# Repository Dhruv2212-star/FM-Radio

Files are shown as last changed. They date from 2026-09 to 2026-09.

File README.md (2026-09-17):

# Dhruv's FM-Radio 
A simple FM radio that can search for channels and connect to them with the given controls from 87-108 MHz that can fit in your palms !  

## Virtual Controls for our radio-  
1.  s = seek up  
2.  S = seek down  
3. "+" = tune +100 kHz  
4.  "-" = tune -100 kHz  
5.  V = increase RDA5807 digital volume  
6.  v = decrease RDA5807 digital volume  
7.  m = mute/unmute  
8.  i = print radio status

**PCB Dimentions- 40mm x 55mm x 1.6 mm**  

# How to use the final Radio?
To use the final radio, connect the microcontroller to your laptop/desktop and flash the firmware on and it'll show a new panel, you can use the above keys for the controls  

## Case
our case is made into 2 parts, the Bottom case and the Top case, the top case will snugly fit on the bottom case because of it's low tolerance 

**Top Case**  


**Bottom Case** 



# Final Assembly 
what our final product will look like (ignore the empty spaces, its for speakers) 
Image of proj

## PCB 


14 09 2026_14 19 05_REC

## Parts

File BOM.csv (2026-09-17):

Ref | Value | Description | Qty | KiCad Symbol | Footprint | India seller | Unit cost (INR) | Buy / product page
U1 | MOUDLE-SEEEDUINO-XIAO | Seeed Studio XIAO RP2040 | 1 | XIAO_RP2040:MOUDLE-SEEEDUINO-XIAO | my footprints:XIAO-Generic-Hybrid-14P-2.54-21X17.8MM | Robocraze | INR 589 | https://robocraze.com/pages/seeed-studio
U2 | RDA5807MRRD-102V2.0 | RDA5807M RRD-102 V2.0 FM module | 1 | Static_Symbol_Library:RDA5807MRRD-102V2.0 | Static:RDA5807 | ElectronicsComp | INR 67.26 | https://www.electronicscomp.com/rda5807m-fm-stereo-radio-module-rrd-102v2.0-wireless-pro-for-arduino-tuner
U3 | TDA2822NBD | TDA2822 dual audio amplifier, DIP-8 | 1 | Static_Symbol_Library:TDA2822NBD | Package_DIP:DIP-8_W7.62mm | Robu.in (equivalent TDA2822M) | INR 9 | https://robu.in/product-category/electronic-components/integrated-circuits/audio-ic/
RV1 | 10K | WH148 10K potentiometer | 1 | Device:R_Potentiometer | Connector:FanPinHeader_1x03_P2.54mm_Vertical | AM Electronics India | INR 12 | https://amelectronics.in/product/10k-potentiometer/
RV2 | 10K | WH148 10K potentiometer | 1 | Device:R_Potentiometer | Connector:FanPinHeader_1x03_P2.54mm_Vertical | AM Electronics India | INR 12 | https://amelectronics.in/product/10k-potentiometer/
C1 | 100uF | 100 µF polarized electrolytic capacitor | 1 | Device:C_Polarized | Capacitor_THT:CP_Radial_D6.3mm_P2.50mm | ElectronicsComp | INR 3.74 | https://www.electronicscomp.com/100uf-16v-electrolytic-capacitor
C2 | 100uF | 100 µF polarized electrolytic capacitor | 1 | Device:C_Polarized | Capacitor_THT:CP_Radial_D6.3mm_P2.50mm | ElectronicsComp | INR 3.74 | https://www.electronicscomp.com/100uf-16v-electrolytic-capacitor
C3 | 100uF | 100 µF polarized electrolytic capacitor | 1 | Device:C_Polarized | Capacitor_THT:CP_Radial_D6.3mm_P2.50mm | ElectronicsComp | INR 3.74 | https://www.electronicscomp.com/100uf-16v-electrolytic-capacitor
C4 | 100uF | 100 µF polarized electrolytic capacitor | 1 | Device:C_Polarized | Capacitor_THT:CP_Radial_D6.3mm_P2.50mm | ElectronicsComp | INR 3.74 | https://www.electronicscomp.com/100uf-16v-electrolytic-capacitor
C5 | 100uF | 100 µF polarized electrolytic capacitor | 1 | Device:C_Polarized | Capacitor_THT:CP_Radial_D6.3mm_P2.50mm | ElectronicsComp | INR 3.74 | https://www.electronicscomp.com/100uf-16v-electrolytic-capacitor
CN1 | PJ-3200 | 3.5 mm stereo audio jack, PJ-3200 | 1 | Static_Symbol_Library:PJ-3200 | Static:AUDIO-TH_PJ-3200 | Evelta | INR 4.72 | https://evelta.com/3-5mm-female-audio-jack-connector-3pin-1/
TP1 | SP1 + | SMD solder pad, 4x4 mm | 1 | Connector:TestPoint | TestPoint:TestPoint_Pad_4.0x4.0mm |  |  | https://kicad.github.io/footprints/TestPoint.html
TP2 | SP - | SMD solder pad, 4x4 mm | 1 | Connector:TestPoint | TestPoint:TestPoint_Pad_4.0x4.0mm |  |  | https://kicad.github.io/footprints/TestPoint.html
TP3 | SP2 + | SMD solder pad, 4x4 mm | 1 | Connector:TestPoint | TestPoint:TestPoint_Pad_4.0x4.0mm |  |  | https://kicad.github.io/footprints/TestPoint.html
TP4 | SP2 - | SMD solder pad, 4x4 mm | 1 | Connector:TestPoint | TestPoint:TestPoint_Pad_4.0x4.0mm |  |  | https://kicad.github.io/footprints/TestPoint.html
TOTAL COST |  |  |  |  |  |  | INR 712.68

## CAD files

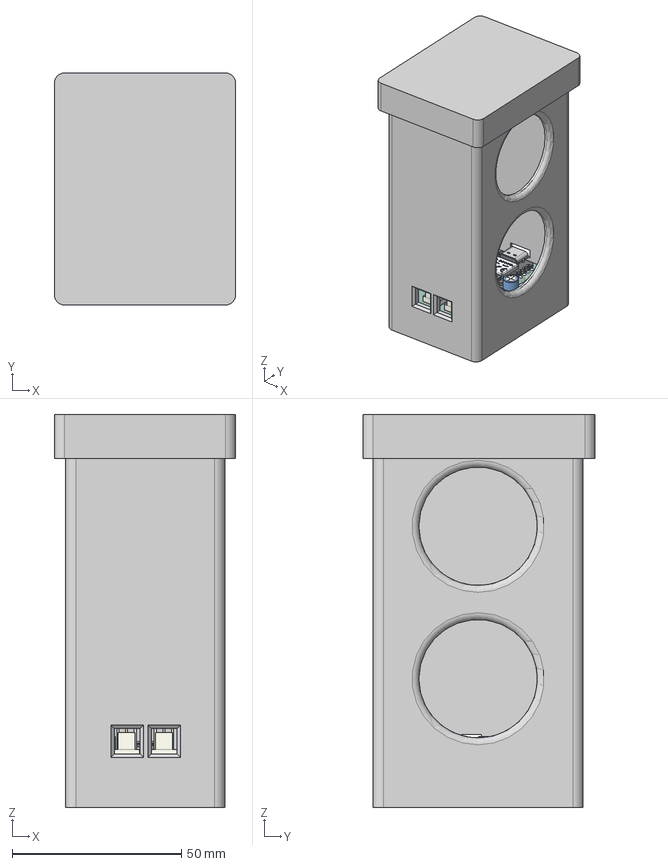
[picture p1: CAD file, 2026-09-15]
Src files/CAD/Assembly File_.step
53.5 x 68.5 x 116.0 mm
Radio_via
Radio_PCB
VSS

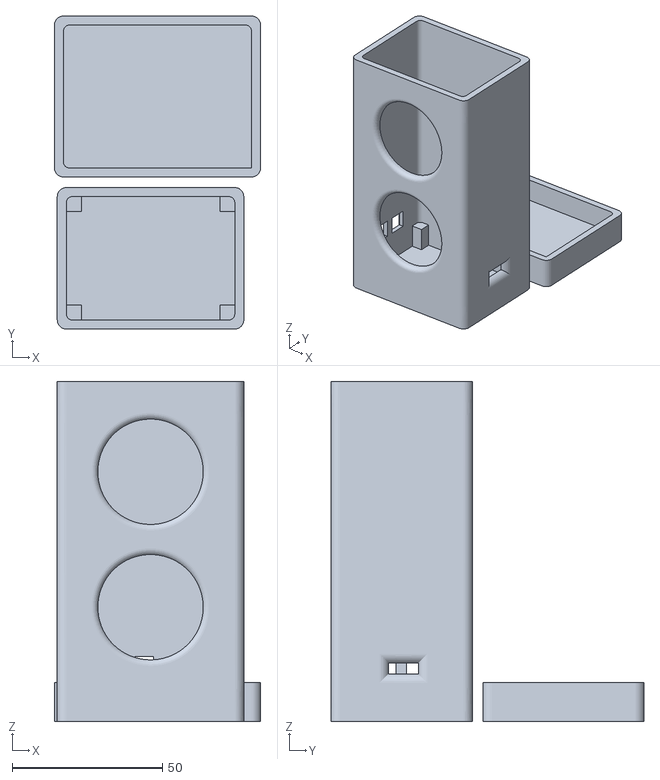
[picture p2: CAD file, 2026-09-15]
Production/Case.stl
68.5 x 104.0 x 113.0

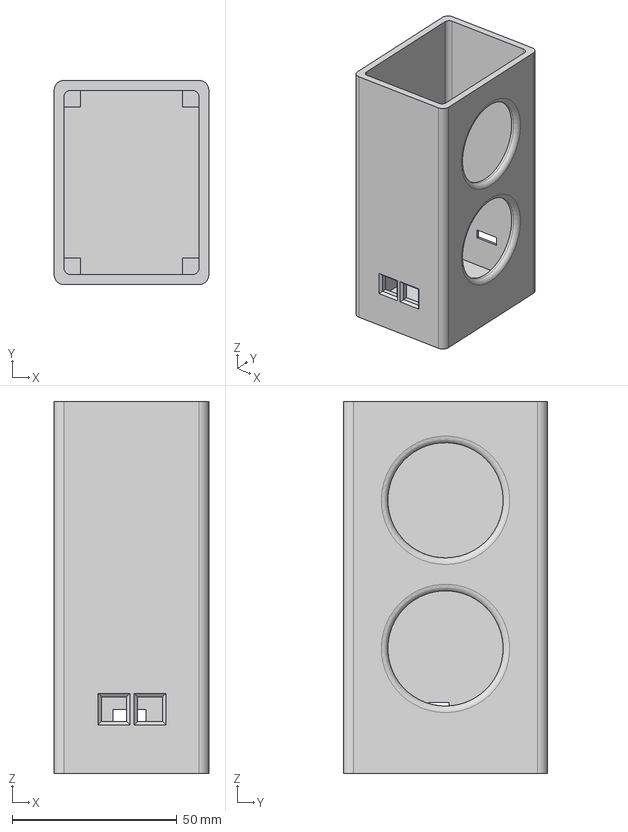
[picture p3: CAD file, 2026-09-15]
Src files/CAD/Case/Bottom case.step
47.0 x 62.0 x 113.0 mm

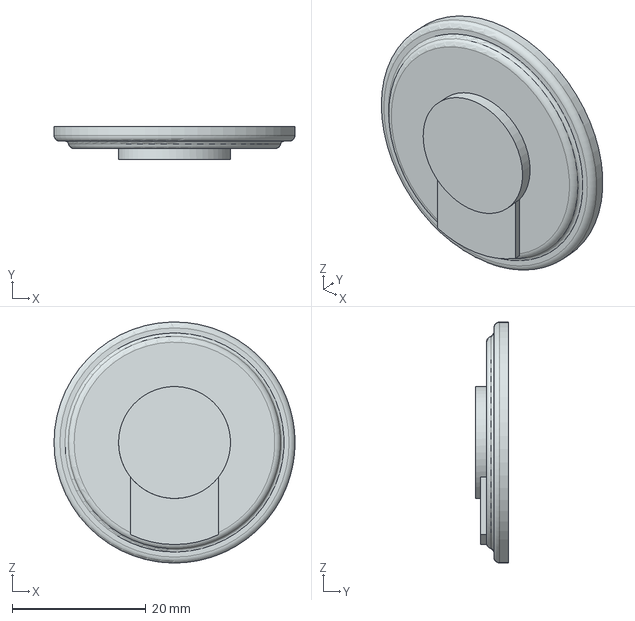
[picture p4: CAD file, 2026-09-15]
Src files/CAD/Models related to PCB/16 ohm 36 mm speaker.stp
36.0 x 4.95 x 36.0 mm

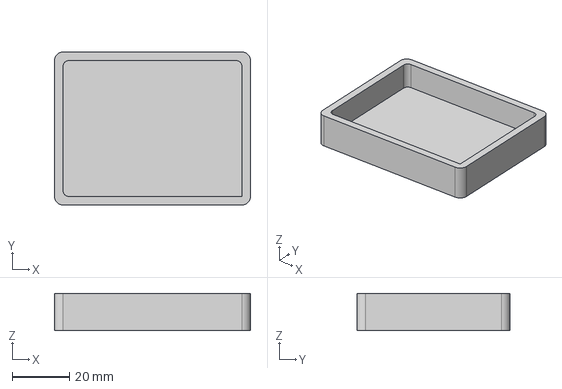
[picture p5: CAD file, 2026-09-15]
Src files/CAD/Case/Top case.step
68.5 x 53.5 x 13.0 mm

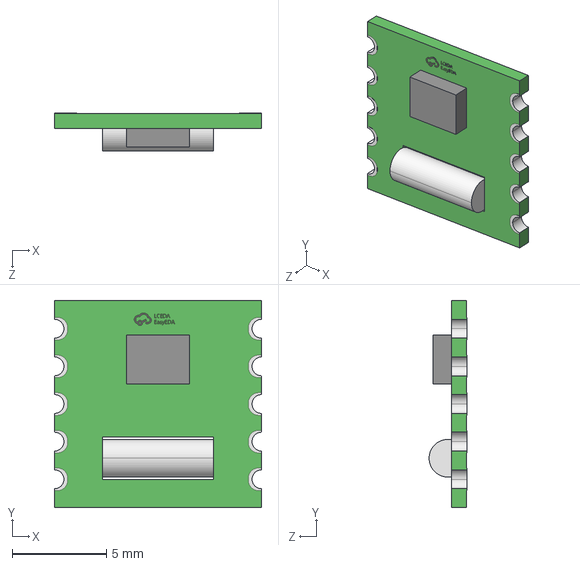
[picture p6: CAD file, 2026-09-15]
Src files/CAD/Models related to PCB/COMM-SMD_L11.0-W11.0-P2.00-TL.step
11.0 x 11.0 x 2.01 mm

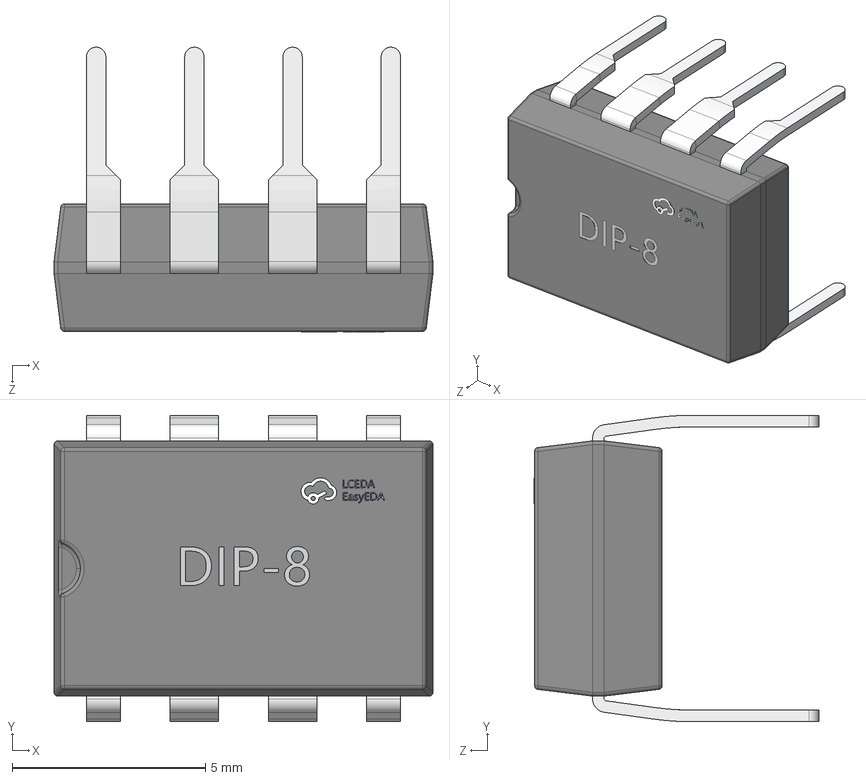
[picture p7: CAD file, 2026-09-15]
Src files/CAD/Models related to PCB/DIP-8_L9.8-W6.6-H3.5-LS7.62-P2.54.step
9.80 x 7.92 x 7.36 mm

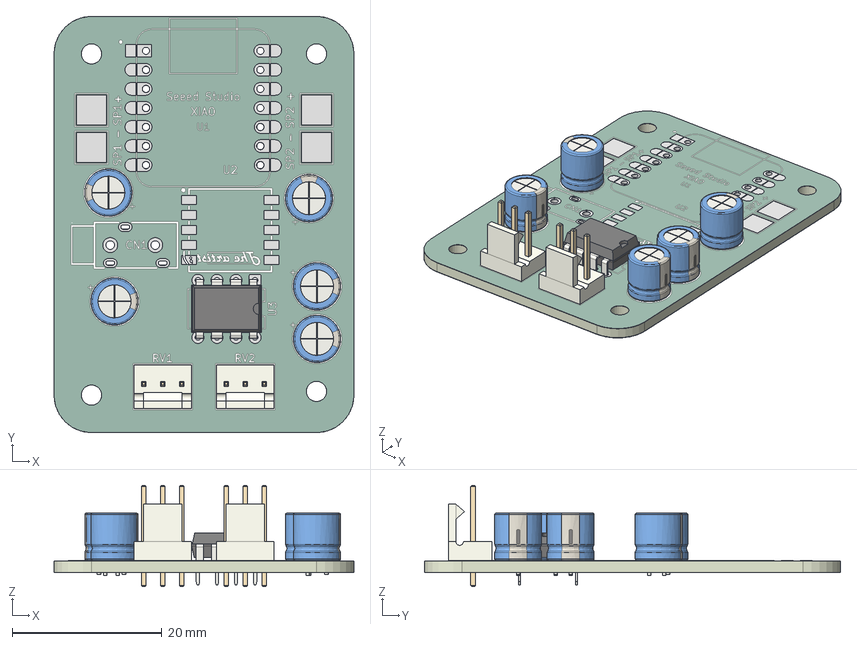
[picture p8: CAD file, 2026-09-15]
Src files/CAD/Models related to PCB/3D Model of PCB.step
40.0 x 55.5 x 13.5 mm
Fan_Pin_Header_Straight_1x03 x 2
CP_Radial_D63mm_P250mm x 5
DIP-8_W7.62mm
Radio_copper
Radio_pad
Radio_via
Radio_silkscreen x 2
Radio_soldermask x 2
Radio_PCB

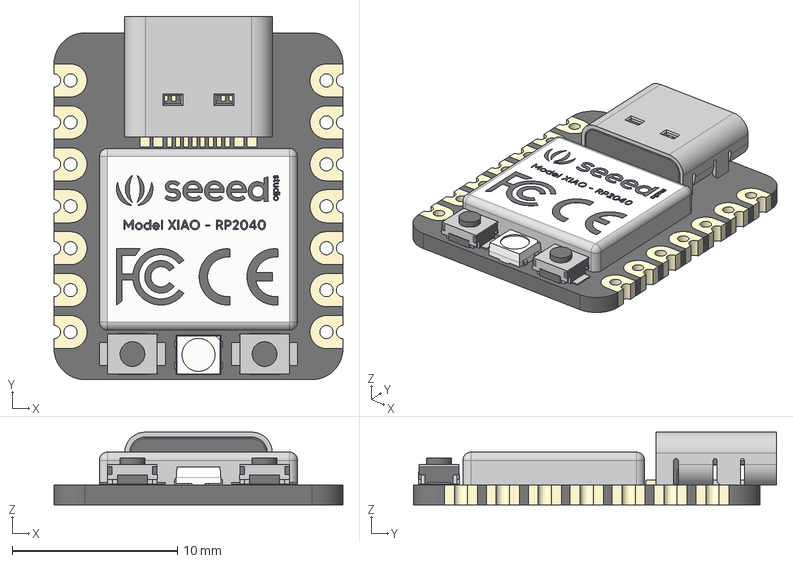
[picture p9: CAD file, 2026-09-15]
Src files/CAD/Models related to PCB/Seeed Studio XIAO RP2040 v26.step
17.5 x 22.0 x 4.40 mm
type-c v2
smd_button v3
DOUT
DIN
VSS
VDD
smd_button v3(Mirror)

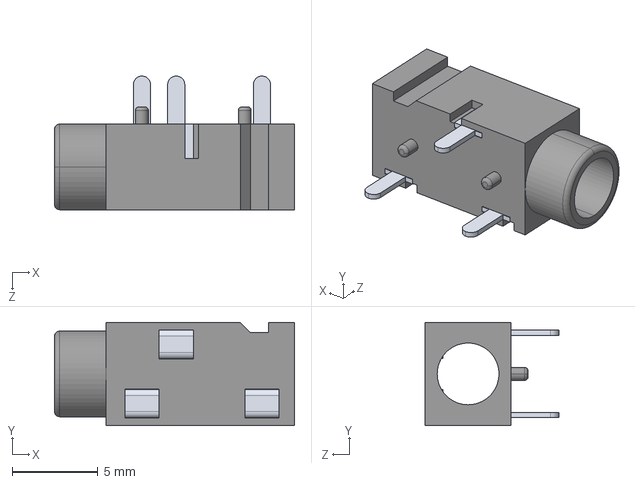
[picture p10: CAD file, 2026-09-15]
Src files/CAD/Models related to PCB/AUDIO-TH_PJ-3200.step
14.0 x 6.01 x 7.81 mm

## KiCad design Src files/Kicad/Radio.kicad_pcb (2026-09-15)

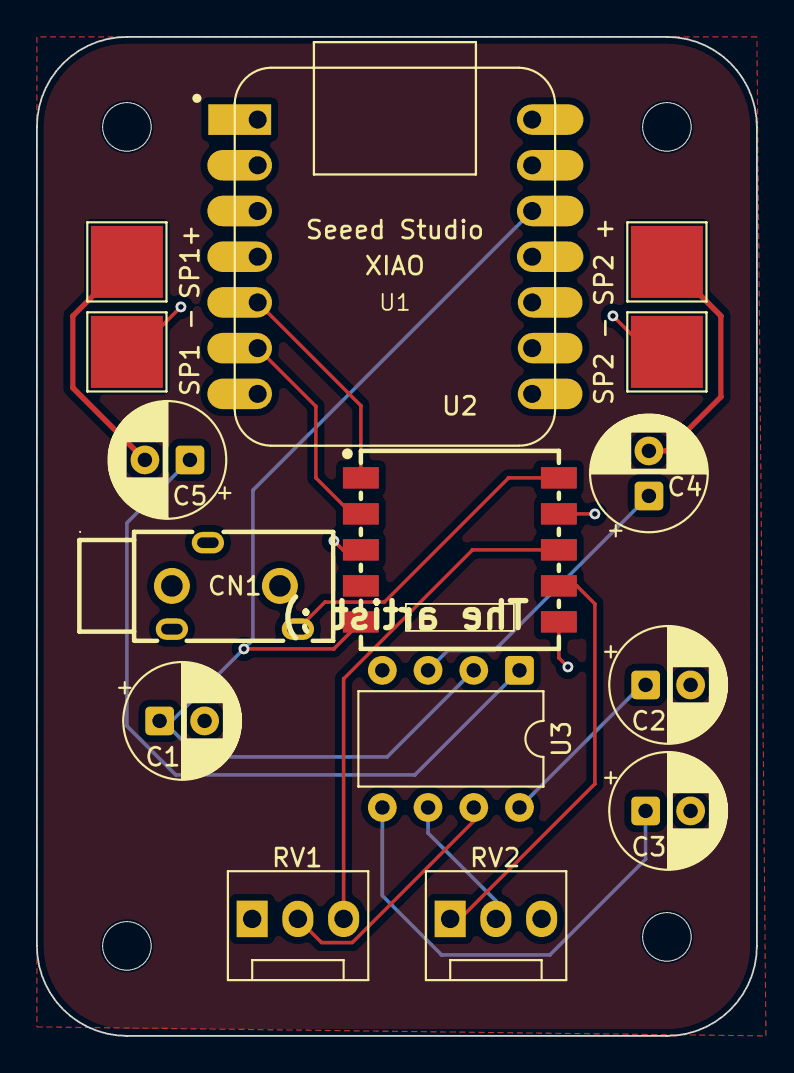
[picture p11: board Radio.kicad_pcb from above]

Board: 2 copper layers, 40.0 x 55.5 mm, 19 parts (0 on the bottom side), 15 nets.

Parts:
C1, C2, C3, C4, C5: 100uF; CP_Radial_D6.3mm_P2.50mm
CN1: PJ-3200; AUDIO-TH_PJ-3200
H1, H2, H3, H4: MountingHole; MountingHole_2.7mm_M2.5
RV1, RV2: 10K; FanPinHeader_1x03_P2.54mm_Vertical
SP1 -: SP -; TestPoint_Pad_4.0x4.0mm
SP1+: SP1 +; TestPoint_Pad_4.0x4.0mm
SP2 +: SP2 +; TestPoint_Pad_4.0x4.0mm
SP2 -: SP2 -; TestPoint_Pad_4.0x4.0mm
U1: MOUDLE-SEEEDUINO-XIAO; XIAO-Generic-Hybrid-14P-2.54-21X17.8MM
U2: RDA5807MRRD-102V2.0; RDA5807
U3: TDA2822NBD; DIP-8_W7.62mm

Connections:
+3V3: C1.1, U1.12 (3V3), U2.5 (VCC), U3.2 (VCC)
/L-OUT: RV2.1, U2.7 (L-OUT)
/R-OUT: RV1.3, U2.8 (R-OUT)
GND: C1.2, C2.2, C3.2, CN1.3, RV1.1, RV2.3, SP1 -.1 (1_1), SP2 -.1 (1_1), U1.13 (GND), U2.3 (GND), U2.6 (GND), U2.9 (GND), U3.4 (GND)
unnamed: C4.2, SP2 +.1 (1_1)
unnamed: C5.2, SP1+.1 (1_1)
unnamed: U1.5 (PA8_A4_D4_SDA), U2.1 (DATA)
unnamed: U1.6 (PA9_A5_D5_SCL), U2.2 (CLK)
unnamed: CN1.4, U2.10 (ANT)
unnamed: RV1.2, U3.7 (IN1)
unnamed: RV2.2, U3.6 (IN2)
unnamed: C2.1, U3.8 (NF1)
unnamed: C3.1, U3.5 (NF2)
unnamed: C5.1, U3.1 (OUT1)
unnamed: C4.1, U3.3 (OUT2)

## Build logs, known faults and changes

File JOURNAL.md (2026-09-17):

*While going through instagram reels, i came across a really cool project in which the guy used just some copper wires and an crystal  
and some earphones to make a DIY radio that you can listen to and i remembered that there was an YSWS where you can make a Radio and get it for yourself  
so i stopped doomscrolling and sat on my PCB and started the initial research.*

- **What was the initial research?**
  well my initial research included watching some examples of DIY radios and i saw the kit and the parts with which i was supposed to
  build it so i started to go through the data sheets and made the final connections roughly and started making the connections on Kicad
  after downloading the resources available on the static website (footprints & symbols)
  
# PCB in kicad | 2 hours  
the main reason why it took so long is because i had to debugg footprint issues again and again and work around with the resistors.  
while making the schematic i realized that the 2 10K resistors that were in the tutorial were pointless for my build so  
i had to remove them as the potentiometers were already connected to the ground and the other thing being the DRC list which kept flagging, and i resized my silkscreen art which took me quite some time to figure out because i later realised that you cannot resize your art so in the end i just remade it again and i kinda had to arrange the components again and again so that was one annoying thing tho.
issues related to footprint so that had to be fixed. also after doing all that i realised that the Gerber files came out incomplete and corrupted so i had to fix that later  
14 09 2026_14 18 17_REC

Lapse: https://lapse.hackclub.com/timelapse/lmbW12xKm2o3  

# Making the Firmware! | 40 mins 
**AI ussage declaration: Ai has been used for writing the skeleton of this firmware because it was hard to start from zero hence i had to learn how the main frimware will work and later i spet time on making my final code**  
i started with the basics which is i searched for the required libs and i got to know that for our build we need 2 main libs- Included Arduino + I²C libraries, so after adding these i started with defining the GPIO pins that i used.  
created the functions to communicate with RDA5807 which includes- write, read and check registers and also check weather the radio is connected or not. i had quite some difficulties trying to figure out the correct funtions for it so i went and looked up some tutorials on YouTube of people doing this and i found the correct required function and loop.  
after that i set the range for our FM radio and the spacings in between the frequency which is 100Khz.  
then i added the radio functions such as- setfrequency, seekstation, set mute, etc. this was quite easy as i had to just google it and i found this part very easy.  
then i set the controls for the radio as give in the README file. this sums up the Firmware process 

# CAD | 1 hour 23 mins
I had to figure out a LOT of things here because i had to take count of the tolerances and the distance for the each opening such as the usb c in which i had to take around 10 measurements from the PCB model just for it to fit properly at it's place and i had to also look up the correct dimensions for the speaker holes because many 1W speakers had different shapes but i set one in the in which were 35mm 1W 8 ohms speakers which were fitting the best for my use so i cut out the holes for fitting them in between the case.  
Final thing was the Top case, it was easy but i messed up twice making it. I made it the same size as the bottom case and the second time i forgot to account for the tolerance making it time taking  
In the end i finished the project with making the assembly file where i fit the PCB, bottom case, and the top case together  
bottom case and assembly took most of the time as setting the correct distance for antenna, potentiometers and the C port for Xiao  





Image of proj

Lapse: https://lapse.hackclub.com/timelapse/YyshfXtkXlj3

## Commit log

2026-09-15 controlls and case
2026-09-15 Development files
    [16 ohm 36 mm speaker.stp, 3D Model of PCB.step, AUDIO-TH_PJ-3200.step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]
2026-09-15 updated CAD
    [Assembly File_.step, Bottom case.step, Case.stl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]
2026-09-16 Assembly image
2026-09-16 Assembly file
    [BOM.csv]
2026-09-17 Upadated BOM
    [BOM.csv]
